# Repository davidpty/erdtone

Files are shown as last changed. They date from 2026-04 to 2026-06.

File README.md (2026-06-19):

# ErdTone

Bring a vintage rotary phone back to life on a modern telephone exchange. ErdTone converts pulse dialing to DTMF tones in real time, running on a single ATtiny85 hidden inside the phone with no visible modifications.

Built around the Siemens W48 with full support for the `Earth key` (German: Erdtaste), it goes beyond basic pulse conversion with last-number redial, speed-dial, Direct Dial Mode, auto-dial on pickup, `*` and `#` hold gestures, pause support, and adjustable DTMF timing. Everything is configured directly from the rotary dial - no computer needed after flashing.

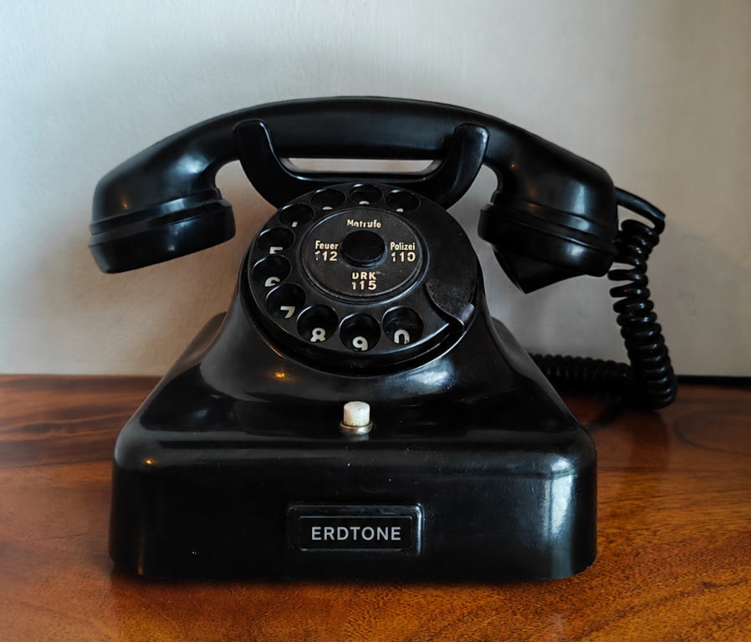
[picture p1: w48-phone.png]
Siemens W48 rotary phone


This project is a fork of the rotarydial firmware, extended with Earth key support, auto-dial, speed-dial, Direct Dial Mode, and configurable DTMF and menu timing.

## Hardware

Needed build parts:

* 1x ATTINY85V
* 1x 78L05 5V regulator
* 1x 4 MHz crystal
* 1x 680 ohm resistor
* 1x 27 V 1 W zener diode
* 2x 22 pF ceramic capacitors
* 4x 0.1 uF (100 nF) ceramic capacitors
* 1x 4 position terminal
* 1x 1N4007 diode

## Circuit

A Fritzing layout is included with a compact footprint designed to fit inside the W48 housing without modifications. See `ErdTone.fzz`.

## Wiring

### Rotary dial

* Disconnect the rotary dial from the phone circuitry. Do not connect it in parallel with the original phone circuit.
* Connect it to the converter:

  * Pulse contact, normally closed and opening for each pulse, to `PULSE`
  * Dial contact, closed while the dial is moving, to `DIAL`

### Earth key

* Disconnect the `Earth key` from the phone circuitry.
* Connect it to the same `DIAL` line used by the rotary dial:

  * One side to `DIAL`
  * Other side to `GND`
* Pressing the `Earth key` must pull `DIAL` to `GND`.

### Power

* Connect power after the hookswitch:

  * Line `+` to `VCC`
  * Line `-` to `GND`
* The device must be off when the phone is on-hook.
* Optional: add a diode, for example 1N4007, between line `+` and `VCC` for protection:

  * Anode to line `+`
  * Cathode to `VCC`

## Build

Install tools:

```bash
sudo apt update && sudo apt install gcc-avr avr-libc binutils-avr avrdude make
```

Build, flash and set fuses:

```bash
make install              # default 4 MHz external crystal
make CLOCK_MODE=8 install # 8 MHz internal oscillator, for testing only
```

Erase EEPROM, clearing all stored numbers and settings:

```bash
make erase
```

## Operation

### Normal dialing

Dial a number and release. The firmware sends the matching DTMF tone.

If you pause for more than about 3 seconds between digits, a pause is automatically inserted into the redial memory at that point. If you wait more than about 6 seconds, two pauses are inserted. This allows redial to correctly replay numbers that require waiting for an automated phone menu or office switchboard to respond.

### Earth key

The `Earth key` is a quick redial and speed-dial shortcut.

* Brief press and release: redial the last number
* Hold until the first beep: dial the stored Earth key speed-dial number
* Hold until the second beep: program the Earth key speed-dial number
* Press during startup: cancel auto-dial for that cycle

### Rotary hold menu

Use the rotary dial for special functions.

Dial a digit and hold until the first beep, then release:

* `1` = send `*`
* `2` = send `#`
* `3` = redial last number
* `4` to `9`, `0` = dial the stored speed-dial number

Keep holding until the second beep:

* `4` to `9`, `0` = enter programming mode for that speed-dial slot
* `1` = cycle DTMF tone duration, 80 ms or 200 ms
* `2` = cycle menu hold time, 1 s or 2 s
* `3` = enter auto-dial setup

### Speed-dial programming

1. Dial the slot digit.
2. Keep holding until the second beep, then release.
3. Enter the number one digit at a time.
4. Release after each digit.
5. Hang up when done.

Notes:

* Each digit is written to EEPROM immediately.
* `*`, `#`, and pause can be stored by dialing `1`, `2`, or `3`, holding until the first beep, then releasing.
* The Earth key has its own dedicated speed-dial slot, programmed by holding the Earth key until the second beep.
* During programming, you can copy into the current slot:

  * Press the `Earth key` to load the last dialed number.
  * Dial a source speed-dial slot, `4` to `9` or `0`, and hold until the first beep.
* Hold `0` until the second beep to clear the current slot. This also works for the Earth key slot.

### Auto-dial setup

Auto-dial is stored in one of the speed-dial slots and dials automatically after power-up if enabled.

Set auto-dial:

1. Dial `3`.
2. Hold until the second beep, then release.
3. Dial the speed-dial slot, or press the `Earth key` to use the Earth key speed-dial number as the auto-dial number.
4. The auto-dial is saved with the default 5 second delay.
5. Optional: dial a delay digit from `0` to `9` to override the delay.

Clear auto-dial:

1. Dial `3`.
2. Hold until the second beep, then release.
3. Hold `0` until the second beep, then release.

Pressing the `Earth key` or starting to dial during startup cancels auto-dial for that cycle.

## Service Codes

Service codes are entered during a normal call using the rotary hold menu for `*` and `#`.

### Direct Dial Mode

Direct Dial Mode turns digits `4` to `9` and `0` into instant speed-dial keys. Pressing any of them immediately dials the stored number without holding. The Earth key also dials its assigned speed-dial slot directly.

Set it up with a 3-digit PIN `PPP`, using digits `0` to `9` only:

* `**PPP` enables Direct Dial with Programming Lock:

  * Normal dialing still works.
  * Speed-dial programming, settings changes, and factory reset are blocked.
* `*#PPP` enables Direct Dial Only:

  * Normal dialing is blocked.
  * Digits `4` to `9` and `0` directly dial their assigned speed-dial slots.
  * The Earth key directly dials the Earth key speed-dial slot.
  * Speed-dial programming, settings changes, and factory reset are blocked.

Disable the active lock mode:

* `**PPP` or `*#PPP` with the correct PIN permanently disables the active lock mode and clears the PIN.
* `##PPP` with the correct PIN temporarily disables the active lock mode for the current call only.

To enter a PIN when Direct Dial Only is active:

1. Dial `*` or `#` twice via first-level hold as the first two actions after pickup.
2. Any combination works: `**`, `##`, `*#`, or `#*`.
3. This arms PIN entry mode.
4. Dial the three PIN digits directly.
5. These digits feed the PIN sequence without triggering any speed-dial slot.

Use `**PPP` or `*#PPP` to permanently disable the active lock mode, or `##PPP` to disable it for the current call only.

### Factory reset

Dial `*#0#*` to erase all stored numbers, speed-dial slots, auto-dial configuration, and reset DTMF duration and menu hold time to defaults.

Factory reset is blocked when a lock mode is active.

## Credits

ErdTone builds on the work of [Boris Cherkasskiy](http://boris0.blogspot.ca/2013/09/rotary-dial-for-digital-age.html), who created the original firmware in 2011, [Arnie Weber](https://bitbucket.org/310weber/rotary_dial/), who reworked the hardware in 2015, and [Matthew Millman](http://tech.mattmillman.com/), who cleaned up the implementation in 2018.

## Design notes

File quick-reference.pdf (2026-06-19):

W48 - ErdTone - Quick Reference

DR: Dial & Release
H1: Hold -> 1st beep
H2: Hold -> 2nd beep

Normal dialing (DR)

DR: 0-9 | DTMF tone sent
Pause >3 s | Stores a pause in redial

Earth key (Erdtaste)

Short press Redial last number

H1 | Dial Earth key slot
H2 | Program Earth key slot
Press at pickup | Cancel auto-dial for this session

H1 actions

H1: 1 | Send *

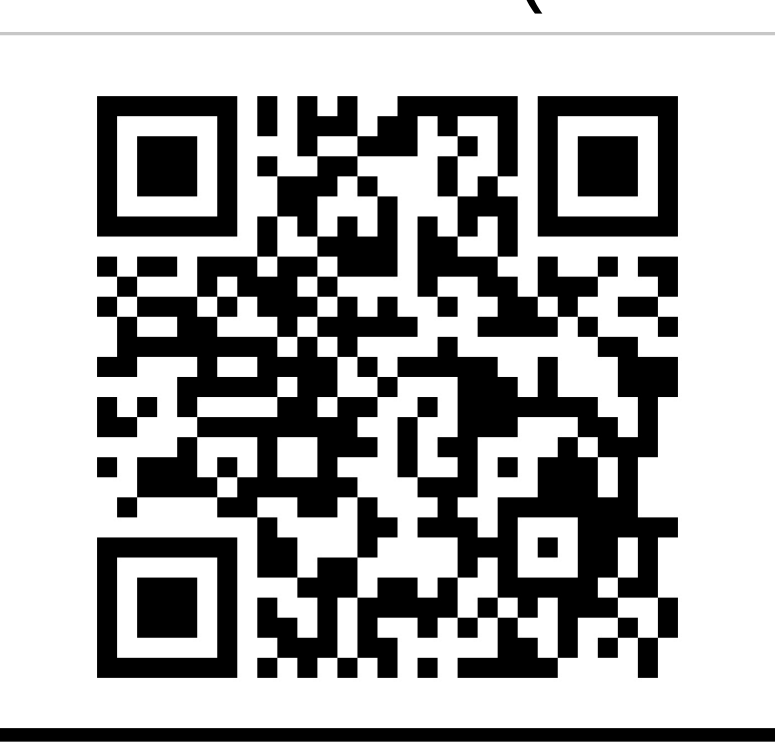
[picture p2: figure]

H1: 2 | Send #
H1: 3 | Redial last number
H1: 4-9,0 | Dial speed-dial slot

Programming (H2 to enter)

H2 actions

H2: 4-9,0 | Enter slot programming
H2: 1 | Toggle DTMF 80/200 ms
H2: 2 | Toggle hold 1/2 s
H2: 3 | Enter auto-dial setup
During slot programming
DR: 0-9 | Store digit
H1: 1 or 2 | Store * or #
H1: 3 | Store pause
H1: 4-9,0 | Copy speed-dial slot
Earth key | Copy last dialed
H2: 0 | Clear this slot
Hang up | Save & exit
During auto-dial setup
1. Select # | Earth key slot or speed-dial slot 4-9, 0
2. Set delay | Dial 0-9 seconds
H2: 0 | Clear auto-dial

Service codes (* # via H1)

Set lock (no PIN set)

**PIN | Lock programming
*#PIN | Lock programming and dialing
PIN | 3 digits from 0-9
Unlock (* # via H1)
**PIN | Permanent unlock
##PIN | Unlock for this call only

Fully locked mode

DR: 4-9,0 | Dial speed-dial

DR: Earth key Dial Earth key slot

DR: 1,2,3 | No action

Factory reset

*#0#* | Erase all (blocked if locked)

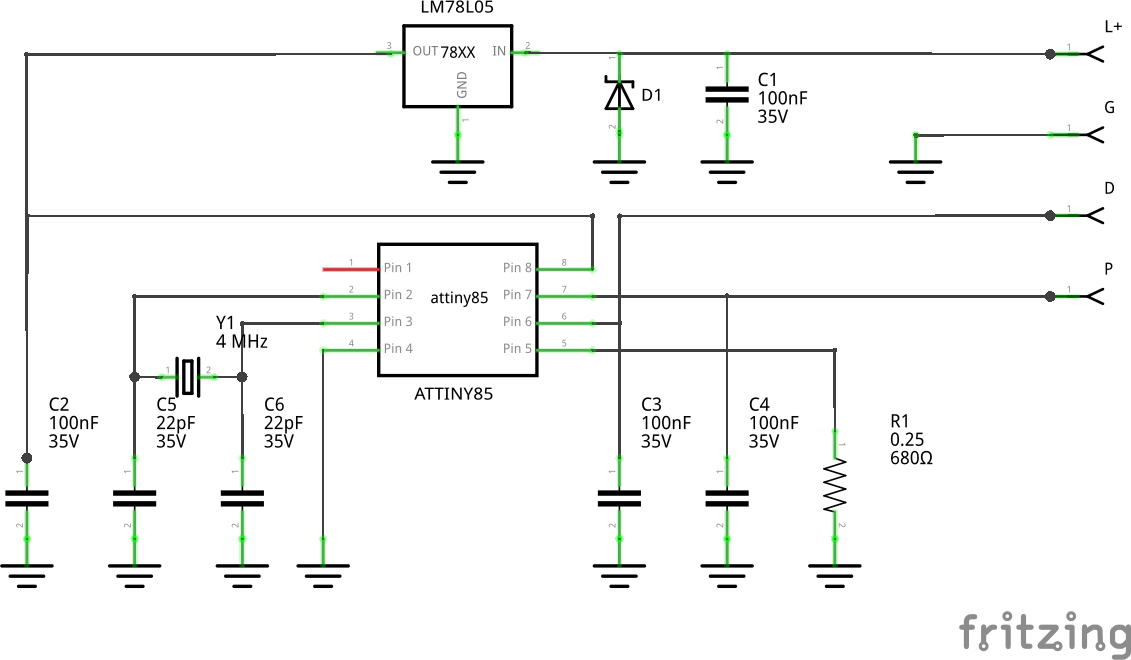
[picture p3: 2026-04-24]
pcb-schematic.png

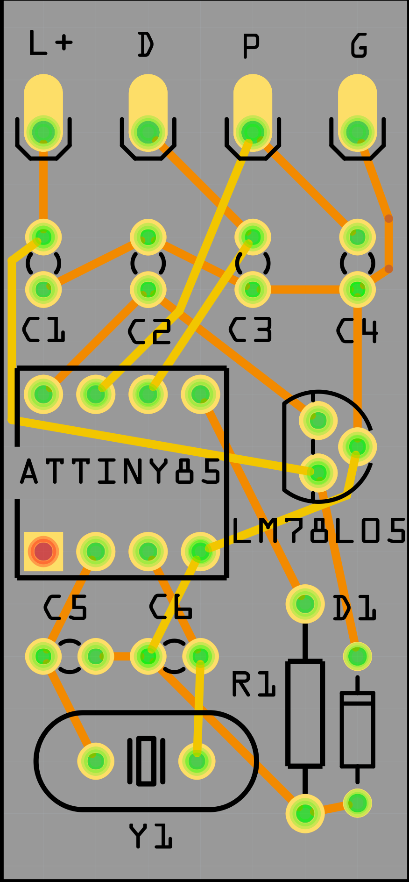
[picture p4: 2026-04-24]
pcb-layout.png

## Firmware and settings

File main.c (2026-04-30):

//*****************************************************************************
// Title        : Pulse to tone (DTMF) converter
// Author       : Boris Cherkasskiy
//                http://boris0.blogspot.ca/2013/09/rotary-dial-for-digital-age.html
// Created      : 2011-10-24
//
// Modified     : Arnie Weber 2015-06-22
//                https://bitbucket.org/310weber/rotary_dial/
//                NOTE: This code is not compatible with Boris's original hardware
//                due to changed pin-out (see Eagle files for details)
//
// Modified     : Matthew Millman 2018-05-29
//                http://tech.mattmillman.com/
//                Cleaned up implementation, modified to work more like the
//                Rotatone commercial product.
//
// Modified     : davidpty 2026-04-23
//                added hotdial, lock dial and support for 'Erdtaste' 
//
// This code is distributed under the GNU Public License
// which can be found at http://www.gnu.org/licenses/gpl.txt
//
// DTMF generator logic is loosely based on the AVR314 app note from Atmel
//
//*****************************************************************************

// Uncomment to build with reverse dial
//#define NZ_DIAL

#include <stdbool.h>
#include <stdint.h>
#include <avr/io.h>
#include <avr/interrupt.h>
#include <avr/sleep.h>
#include <avr/wdt.h>
#include <util/delay.h>
#include <avr/eeprom.h>
#include <string.h>

#include "dtmf.h" 

#define PIN_DIAL                    PB1
#define PIN_PULSE                   PB2

#define SPEED_DIAL_SIZE             42

#define STATE_DIAL                  0x00
#define STATE_SPECIAL_L1            0x01
#define STATE_SPECIAL_L2            0x02
#define STATE_PROGRAM_SD            0x03
#define STATE_HOTLINE_SLOT          0x04
#define STATE_HOTLINE_DELAY         0x05
#define STATE_PROGRAM_ERDTASTE      0x06

#define F_NONE                      0x00
#define F_DETECT_SPECIAL_L1         0x01
#define F_DETECT_SPECIAL_L2         0x02
#define F_WDT_AWAKE                 0x04

#define SLEEP_64MS                  0x00
#define SLEEP_128MS                 0x01
#define SLEEP_1S                    0x02
#define SLEEP_2S                    0x03

#define SPECIAL_L2_HOLD_TIME        SLEEP_2S

#define DTMF_DURATION_MS_SHORT      80
#define DTMF_DURATION_MS_LONG       200
#define DTMF_PAUSE_MS               2000  // Pause inserted in speed dial memory

#define PAUSE_DETECT_HOLD_TIME      SLEEP_2S  // ~2s WDT interval for pause detection
#define F_DETECT_PAUSE              0x08

#define SPEED_DIAL_COUNT            9   // 9 Positions in total (Redail(3),4,5,6,7,8,9,0 and Erdtaste)
#define SPEED_DIAL_ERDTASTE         (SPEED_DIAL_COUNT - 2)   // slot 7
#define SPEED_DIAL_REDIAL           (SPEED_DIAL_COUNT - 1)   // slot 8

#define L2_STAR                     1
#define L2_POUND                    2
#define L2_REDIAL                   3

#define LOCK_NONE                   0
#define LOCK_PROGRAM                1
#define LOCK_FULL                   2

typedef struct
{
    uint8_t enabled;
    uint8_t slot_digit;
    uint8_t delay_digit;
} hotline_config_t;

typedef struct
{
    uint8_t state;
    uint8_t flags;
    bool dial_pin_state;
    bool suppress_first_release;
    bool program_special_insert;
    bool special_l1_latched;
    uint8_t lock_state;
    int8_t speed_dial_digits[SPEED_DIAL_SIZE];
    int8_t dialed_digit;
    int8_t service_code_buf[5];
    uint8_t special_hold_state;
    uint8_t speed_dial_index;
    uint8_t speed_dial_digit_index;
    uint8_t hotline_slot_digit;
    uint8_t l1_hold_time;
    uint8_t pending_pauses;
    uint16_t dtmf_duration;
} runstate_t;

static void init(void);
static void process_dialed_digit(runstate_t *rs);
static void read_speed_dial(uint8_t slot, int8_t *buf);
static void write_speed_dial(uint8_t slot, int8_t *buf);
static uint8_t find_end(int8_t *buf);
static void load_into_current_slot(int8_t *src, runstate_t *rs);
static bool is_programming_state(uint8_t state);
static uint8_t current_program_slot(runstate_t *rs);
static void clear_current_program_buffer(runstate_t *rs);
static void store_digit_to_redial(runstate_t *rs, int8_t digit);
static void push_to_service_buffer(runstate_t *rs, int8_t digit);
static void clear_speed_dial_slot(runstate_t *rs, uint8_t slot_index);
static void append_digit_to_slot(runstate_t *rs, int8_t digit, uint8_t tone);
static void handle_dial_state(runstate_t *rs, int8_t *digit_to_buffer);
static bool handle_program_special_insert(runstate_t *rs);
static bool handle_special_l1_state(runstate_t *rs, int8_t *digit_to_buffer);
static void handle_special_l2_state(runstate_t *rs);
static void handle_programming_state(runstate_t *rs);
static void handle_hotline_slot_state(runstate_t *rs);
static void handle_hotline_delay_state(runstate_t *rs);
static void load_hotline_config(hotline_config_t *config);
static void write_hotline_config(const hotline_config_t *config);
static uint16_t hotline_delay_ms(uint8_t delay_digit);
static bool wait_for_hotline_window(uint16_t delay_ms);
static void suppress_first_release_if_needed(runstate_t *rs, bool dial_pin_state);
static void maybe_dial_hotline(void);
static void dial_speed_dial_number(int8_t *speed_dial_digits, int8_t index, uint16_t dtmf_duration);
static void flush_pending_pauses(runstate_t *rs);
static void check_service_codes(runstate_t *rs);
static void handle_factory_reset(runstate_t *rs);
static bool dial_locked(runstate_t *rs);
static bool programming_locked(runstate_t *rs);
static bool pin_matches(runstate_t *rs, const uint8_t *pin);
static void clear_lock(runstate_t *rs);
static void handle_lock_code(runstate_t *rs, uint8_t requested_lock);
static void handle_session_unlock(runstate_t *rs);
static void wdt_timer_start(uint8_t delay);
static void start_sleep(void);
static void wdt_stop(void);
static bool in_pin_entry_mode(runstate_t *rs);

// Map speed dial numbers to memory locations
const int8_t _g_speed_dial_loc[] =
{
    0,
    -1 /* 1 - * */,
    -1 /* 2 - # */,
    -1 /* 3 - Redial */,
    1,
    2,
    3,
    4,
    5,
    6 
};

typedef struct
{
    int8_t code[5];
    uint8_t action;
} service_code_t;

#define SERVICE_FACTORY_RESET   0

static const service_code_t _g_service_codes[] =
{
    { { DIGIT_STAR, DIGIT_POUND, 0, DIGIT_POUND, DIGIT_STAR }, SERVICE_FACTORY_RESET },
};

int8_t EEMEM _g_speed_dial_eeprom[SPEED_DIAL_COUNT][SPEED_DIAL_SIZE] = { [0 ... (SPEED_DIAL_COUNT - 1)][0 ... SPEED_DIAL_SIZE - 1] = DIGIT_OFF };
hotline_config_t EEMEM _g_hotline_eeprom = { 0, 0, 5 };
uint8_t EEMEM _g_dtmf_duration_eeprom = 0;   // 0=DTMF_DURATION_MS_SHORT, 1=DTMF_DURATION_MS_LONG
uint8_t EEMEM _g_l1_hold_time_eeprom = 0;    // 0=SPECIAL_L1_HOLD_TIME_LONG, 1=SPECIAL_L1_HOLD_TIME_SHORT
uint8_t EEMEM _g_lock_pin_eeprom[3] = { DIGIT_OFF, DIGIT_OFF, DIGIT_OFF };
uint8_t EEMEM _g_lock_state_eeprom = 0;
runstate_t _g_run_state;

int main(void)
{
    runstate_t *rs = &_g_run_state;
    bool dial_pin_prev_state;
    rs->pending_pauses = 0;
    uint8_t lock_state = eeprom_read_byte(&_g_lock_state_eeprom);
    if (lock_state > LOCK_FULL) lock_state = LOCK_NONE;
    rs->lock_state = lock_state;
    init();

    // Wait for the decoupling capacitors to charge
    wdt_timer_start(SLEEP_128MS);
    start_sleep();
    wdt_stop();

    dtmf_init();

    // Local dial status variables 
    rs->state = STATE_DIAL;
    rs->dial_pin_state = true;
    rs->flags = F_NONE;
    rs->special_hold_state = STATE_DIAL;
    rs->suppress_first_release = false;
    rs->special_l1_latched = false;
    for (uint8_t i = 0; i < 5; i++)
        rs->service_code_buf[i] = DIGIT_OFF;
    rs->program_special_insert = false;
    rs->speed_dial_digit_index = 0;
    rs->speed_dial_index = 0;
    rs->hotline_slot_digit = DIGIT_OFF;

    uint8_t dtmf_dur_index = eeprom_read_byte(&_g_dtmf_duration_eeprom);
    if (dtmf_dur_index >= 2) dtmf_dur_index = 0;
    rs->dtmf_duration = (dtmf_dur_index == 0) ? DTMF_DURATION_MS_SHORT : DTMF_DURATION_MS_LONG;

    uint8_t l1_hold_index = eeprom_read_byte(&_g_l1_hold_time_eeprom);
    if (l1_hold_index >= 2) l1_hold_index = 0;
    rs->l1_hold_time = (l1_hold_index == 0) ? SLEEP_2S : SLEEP_1S;
    
    dial_pin_prev_state = true;
    
    for (uint8_t i = 0; i < SPEED_DIAL_SIZE; i++)
        rs->speed_dial_digits[i] = DIGIT_OFF;

//#define DEBUG
    #ifdef DEBUG
        // DEBUG: beep speed_dial_digit_index times to show redial buffer fill level
        {
            int8_t tmp[SPEED_DIAL_SIZE];
            read_speed_dial(SPEED_DIAL_REDIAL, tmp);
            uint8_t count = 0;
            while (count < SPEED_DIAL_SIZE && tmp[count] != DIGIT_OFF)
                count++;
            for (uint8_t i = 0; i < count; i++)
            {
                dtmf_generate_tone(DIGIT_BEEP_LOW, 80);
                sleep_ms(200);
            }
            sleep_ms(1000);
        }
    #endif

    maybe_dial_hotline();

    while (1)
    {
        rs->dial_pin_state = bit_is_set(PINB, PIN_DIAL);

        bool suppressed = rs->suppress_first_release;

        suppress_first_release_if_needed(rs, rs->dial_pin_state);
        if (rs->special_l1_latched && !rs->dial_pin_state)
        {
            dial_pin_prev_state = rs->dial_pin_state;
            continue;
        }
        // Skip if flag was set BEFORE clearing - prevents redial on first release
        if (suppressed)
        {
            dial_pin_prev_state = rs->dial_pin_state;
            continue;
        }

        if (dial_pin_prev_state != rs->dial_pin_state) 
        {
            if (!rs->dial_pin_state) 
            {
                // Dial just started
                if (!rs->special_l1_latched)
                    rs->flags |= F_DETECT_SPECIAL_L1;
                rs->flags &= ~F_DETECT_PAUSE; 
                rs->dialed_digit = 0;
 
                wdt_timer_start(SLEEP_64MS);
                start_sleep();
            }
            else 
            {
                // Disable SF detection (should be already disabled)
                rs->flags &= ~(F_DETECT_SPECIAL_L1 | F_DETECT_SPECIAL_L2);

                // Check that we detect a valid digit
                if (rs->dialed_digit <= 0 || rs->dialed_digit > 10)
                {
                    rs->dialed_digit = DIGIT_OFF;
    
                    if (rs->state == STATE_SPECIAL_L1)
                    {
                        // Erdtaste L1 - dial Erdtaste speed dial
                        wdt_stop();
                        dial_speed_dial_number(rs->speed_dial_digits, SPEED_DIAL_ERDTASTE, rs->dtmf_duration);
                        rs->state = STATE_DIAL;
                    }
                    else if (rs->state == STATE_SPECIAL_L2)
                    {
                        if (programming_locked(rs))
                        {
                            dtmf_generate_tone(DIGIT_TUNE_DESC, 200);
                            rs->state = STATE_DIAL;
                        }
                        else
                        {
                            // Erdtaste L2 - enter Erdtaste speed dial programming
                            wdt_stop();
                            rs->speed_dial_index = SPEED_DIAL_ERDTASTE;
                            rs->special_hold_state = STATE_PROGRAM_ERDTASTE;
                            clear_current_program_buffer(rs);
                            rs->state = STATE_PROGRAM_ERDTASTE;
                        }
                    }
                    else if (is_programming_state(rs->state))
                    {
                        // Erdtaste short press during programming - load redial into buffer
                        wdt_stop();
                        read_speed_dial(SPEED_DIAL_REDIAL, rs->speed_dial_digits);
                        load_into_current_slot(rs->speed_dial_digits, rs);
                        // Stay in current programming state
                    }        
                    else if (rs->state == STATE_HOTLINE_SLOT)
                    {
                        // Erdtaste short press during hotline slot selection - use Erdtaste slot as hotline
                        wdt_stop();
                        rs->hotline_slot_digit = DIGIT_OFF;  // no dial digit, special marker
                        rs->state = STATE_HOTLINE_DELAY;
                        dtmf_generate_tone(DIGIT_BEEP_LOW, rs->dtmf_duration);

                        hotline_config_t config;
                        config.enabled = 1;
                        config.slot_digit = DIGIT_OFF;  // special value meaning Erdtaste slot
                        config.delay_digit = 5;
                        write_hotline_config(&config);
                    }                                    
                    else if (rs->state == STATE_DIAL && !rs->suppress_first_release)
                    {
                        wdt_stop();
                        if (dial_locked(rs))
                        {
                            // Locked: Erdtaste dials the Erdtaste speed-dial slot directly
                            dial_speed_dial_number(rs->speed_dial_digits, SPEED_DIAL_ERDTASTE, rs->dtmf_duration);
                        }
                        else
                        {
                            // Normal: Erdtaste triggers redial
                            read_speed_dial(SPEED_DIAL_REDIAL, rs->speed_dial_digits);
                            dial_speed_dial_number(rs->speed_dial_digits, SPEED_DIAL_REDIAL, rs->dtmf_duration);
                        }
                    }
                    else
                    {
                        rs->suppress_first_release = false;
                        wdt_timer_start(SLEEP_64MS);
                        start_sleep();
                    }
                }
                else 
                {
                    // Got a valid digit - process it            
#ifdef NZ_DIAL
                    // NZPO Phones only. 0 is same as GPO but 1-9 are reversed.
                    rs->dialed_digit = (10 - rs->dialed_digit);
#else
                    if (rs->dialed_digit == 10)
                        rs->dialed_digit = 0; // 10 pulses => 0
#endif
                    wdt_timer_start(SLEEP_128MS);
                    start_sleep();
                    wdt_stop();

                    process_dialed_digit(rs);
                }

                rs->special_l1_latched = false;
            }    
        } 
        else 
        {
            if (rs->dial_pin_state) 
            {
                // Rotary dial at the rest position
                // Reset all variables
                rs->state = STATE_DIAL;
                rs->special_hold_state = STATE_DIAL;
                rs->flags &= ~(F_DETECT_SPECIAL_L1 | F_DETECT_SPECIAL_L2);
                rs->dialed_digit = DIGIT_OFF;
            }
        }

        dial_pin_prev_state = rs->dial_pin_state;

        // Don't power down if special function detection is active        
        if (rs->flags & F_DETECT_SPECIAL_L1)
        {
            rs->flags &= ~F_WDT_AWAKE;
            // Put MCU to sleep - to be awoken either by pin interrupt or WDT
            wdt_timer_start(rs->l1_hold_time);
            start_sleep();

            // Special function mode detected?
            if (rs->flags & F_WDT_AWAKE)
            {
                // SF mode detected
                rs->flags &= ~F_WDT_AWAKE;
                rs->special_hold_state = rs->state;
                if (is_programming_state(rs->state))
                    rs->program_special_insert = true;
                rs->state = STATE_SPECIAL_L1;
                rs->flags &= ~F_DETECT_SPECIAL_L1;
                if (!programming_locked(rs))
                    rs->flags |= F_DETECT_SPECIAL_L2;
                else
                {
                    rs->special_l1_latched = true;
                    wdt_stop();
                }

                // Indicate that we entered L1 SF mode with short beep
                dtmf_generate_tone(DIGIT_BEEP_LOW, 200);
            }
            else
            {
                // Released before the first timeout: cancel special detection so a
                // short press can be handled as redial on the next loop.
                rs->flags &= ~F_DETECT_SPECIAL_L1;
            }
        }
        else if (rs->flags & F_DETECT_SPECIAL_L2)
        {
            rs->flags &= ~F_WDT_AWAKE;
            // Put MCU to sleep - to be awoken either by pin interrupt or WDT
            wdt_timer_start(SPECIAL_L2_HOLD_TIME);
            start_sleep();

            if (rs->flags & F_WDT_AWAKE)
            {
                // SF mode detected
                rs->flags &= ~F_WDT_AWAKE;
                rs->state = STATE_SPECIAL_L2;
                rs->flags &= ~F_DETECT_SPECIAL_L2;

                // Indicate that we entered L2 SF mode with asc tone
                dtmf_generate_tone(DIGIT_TUNE_ASC, 200);
            }
            else
            {
                // Released before the second timeout: cancel special detection.
                rs->flags &= ~F_DETECT_SPECIAL_L2;
            }
        }        
        else if (rs->flags & F_DETECT_PAUSE)
        {
            rs->flags &= ~F_WDT_AWAKE;
            wdt_timer_start(PAUSE_DETECT_HOLD_TIME);
            start_sleep();

            if (rs->flags & F_WDT_AWAKE)
            {
                rs->flags &= ~F_WDT_AWAKE;
                if (rs->pending_pauses < 2)
                {
                    rs->pending_pauses++;
                    if (rs->pending_pauses >= 2)
                    {
                        rs->flags &= ~F_DETECT_PAUSE;  // max pauses reached, stop
                        wdt_stop();
                    }
                        
                }
            }
            else
            {
                // Woken by pin interrupt (dial activity) - cancel pause detection
                rs->flags &= ~F_DETECT_PAUSE;
            }
        }
        else
        {
            // Don't need timer - sleep to power down mode
            set_sleep_mode(SLEEP_MODE_PWR_DOWN);
            sleep_mode();
        }
    }

    return 0;
}

// New speed-dial buffer helpers: keep EEPROM layout and END-marker behavior centralized.
static void read_speed_dial(uint8_t slot, int8_t *buf)
{
    if (slot < SPEED_DIAL_COUNT)
        eeprom_read_block(buf, &_g_speed_dial_eeprom[slot][0], SPEED_DIAL_SIZE);
}

static void write_speed_dial(uint8_t slot, int8_t *buf)
{
    if (slot < SPEED_DIAL_COUNT)
        eeprom_update_block(buf, &_g_speed_dial_eeprom[slot][0], SPEED_DIAL_SIZE);
}

static uint8_t find_end(int8_t *buf)
{
    uint8_t index = 0;

    while (index < SPEED_DIAL_SIZE && buf[index] >= 0)
        index++;

    return index;
}

static bool is_programming_state(uint8_t state)
{
    return state == STATE_PROGRAM_SD || state == STATE_PROGRAM_ERDTASTE;
}

static uint8_t current_program_slot(runstate_t *rs)
{
    if (rs->state == STATE_PROGRAM_ERDTASTE || rs->special_hold_state == STATE_PROGRAM_ERDTASTE)
        return SPEED_DIAL_ERDTASTE;

    return rs->speed_dial_index;
}

static void clear_current_program_buffer(runstate_t *rs)
{
    for (uint8_t i = 0; i < SPEED_DIAL_SIZE; i++)
        rs->speed_dial_digits[i] = DIGIT_OFF;

    rs->speed_dial_digit_index = 0;
}

static void load_into_current_slot(int8_t *src, runstate_t *rs)
{
    for (uint8_t i = 0; i < SPEED_DIAL_SIZE; i++)
        rs->speed_dial_digits[i] = src[i];

    rs->speed_dial_digit_index = find_end(rs->speed_dial_digits);
    write_speed_dial(current_program_slot(rs), rs->speed_dial_digits);

    for (uint8_t i = 0; i < rs->speed_dial_digit_index; i++)
    {
        dtmf_generate_tone(DIGIT_BEEP_LOW, rs->dtmf_duration);
        sleep_ms(rs->dtmf_duration);
    }
}

static void store_digit_to_redial(runstate_t *rs, int8_t digit)
{
    if (rs->speed_dial_digit_index < SPEED_DIAL_SIZE)
    {
        rs->speed_dial_digits[rs->speed_dial_digit_index] = digit;
        rs->speed_dial_digit_index++;
        write_speed_dial(SPEED_DIAL_REDIAL, rs->speed_dial_digits);
        if (digit != DIGIT_PAUSE)
        {
            rs->pending_pauses = 0;
            rs->flags |= F_DETECT_PAUSE;
        }
    }
}

static void push_to_service_buffer(runstate_t *rs, int8_t digit)
{
    for (uint8_t i = 0; i < 4; i++) {
        rs->service_code_buf[i] = rs->service_code_buf[i + 1];
    }
    rs->service_code_buf[4] = digit;
}
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

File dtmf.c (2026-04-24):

//*****************************************************************************
// Title        : Pulse to tone (DTMF) converter
// Author       : Boris Cherkasskiy
//                http://boris0.blogspot.ca/2013/09/rotary-dial-for-digital-age.html
// Created      : 2011-10-24
//
// Modified     : Arnie Weber 2015-06-22
//                https://bitbucket.org/310weber/rotary_dial/
//                NOTE: This code is not compatible with Boris's original hardware
//                due to changed pin-out (see Eagle files for details)
//
// Modified     : Matthew Millman 2018-05-29
//                http://tech.mattmillman.com/
//                Cleaned up implementation, modified to work more like the
//                Rotatone product.
//
// This code is distributed under the GNU Public License
// which can be found at http://www.gnu.org/licenses/gpl.txt
//
// DTMF generator logic is loosely based on the AVR314 app note from Atmel
//
//*****************************************************************************

#include <stdbool.h>
#include <stdint.h>
#include <avr/interrupt.h>
#include <avr/sleep.h>

#include "dtmf.h"

#define TIMER_CLK_DIV1              0x01    ///< Timer clocked at F_CPU
#define TIMER_PRESCALE_MASK0        0x07    ///< Timer Prescaler Bit-Mask
#define NUM_SAMPLES                 128     // Number of samples in lookup table


static void dtmf_enable_pwm(void);

//************************** SIN TABLE *************************************
// Samples table : one period sampled on 128 samples and
// quantized on 7 bit
//**************************************************************************
const uint8_t auc_sin_param[NUM_SAMPLES] = {
    64,  67,  70,  73,
    76,  79,  82,  85,
    88,  91,  94,  96,
    99,  102, 104, 106,
    109, 111, 113, 115,
    117, 118, 120, 121,
    123, 124, 125, 126,
    126, 127, 127, 127,
    127, 127, 127, 127,
    126, 126, 125, 124,
    123, 121, 120, 118,
    117, 115, 113, 111,
    109, 106, 104, 102,
    99,  96,  94,  91,
    88,  85,  82,  79,
    76,  73,  70,  67,
    64,  60,  57,  54,
    51,  48,  45,  42,
    39,  36,  33,  31,
    28,  25,  23,  21,
    18,  16,  14,  12,
    10,  9,   7,   6,
    4,   3,   2,   1,
    1,   0,   0,   0,
    0,   0,   0,   0,
    1,   1,   2,   3,
    4,   6,   7,   9,
    10,  12,  14,  16,
    18,  21,  23,  25,
    28,  31,  33,  36,
    39,  42,  45,  48,
    51,  54,  57,  60
};

//***************************  x_SW  ***************************************
// Fck = Xtal/prescaler
// Table of x_SW (excess 8): x_SW = ROUND(8 * N_samples * f * 510 / Fck)
//**************************************************************************

// high frequency
// 1209hz  ---> x_SW = 79
// 1336hz  ---> x_SW = 87
// 1477hz  ---> x_SW = 96
// 1633hz  ---> x_SW = 107
//
// low frequency
// 697hz  ---> x_SW = 46
// 770hz  ---> x_SW = 50
// 852hz  ---> x_SW = 56
// 941hz  ---> x_SW = 61
//
//      | 1209 | 1336 | 1477 | 1633
//  697 |   1  |  2   |   3  |   A
//  770 |   4  |  5   |   6  |   B
//  852 |   7  |  8   |   9  |   C
//  941 |   *  |  0   |   #  |   D

#if F_CPU == 8000000
const uint8_t auc_frequency[12][2] =
{
    { 44, 31 }, // 0
    { 40, 23 }, // 1
    { 44, 23 }, // 2
    { 48, 23 }, // 3
    { 40, 25 }, // 4
    { 44, 25 }, // 5
    { 48, 25 }, // 6
    { 40, 28 }, // 7
    { 44, 28 }, // 8
    { 48, 28 }, // 9
    { 40, 31 }, // *
    { 48, 31 }, // #
};
#else
const uint8_t auc_frequency[12][2] =
{
    { 87, 61 }, // 0
    { 79, 46 }, // 1
    { 87, 46 }, // 2
    { 96, 46 }, // 3
    { 79, 50 }, // 4
    { 87, 50 }, // 5
    { 96, 50 }, // 6
    { 79, 56 }, // 7
    { 87, 56 }, // 8
    { 96, 56 }, // 9
    { 79, 61 }, // *
    { 96, 61 }, // #
};
#endif

volatile uint32_t _g_delay_counter;         // Delay counter for sleep function
volatile uint8_t _g_stepwidth_a;                // step width of high frequency
volatile uint8_t _g_stepwidth_b;                // step width of low frequency
volatile uint16_t _g_cur_sin_val_a;             // position freq. A in LUT (extended format)
volatile uint16_t _g_cur_sin_val_b;             // position freq. B in LUT (extended format)

void dtmf_init(void)
{
    TIMSK = _BV(TOIE0);                 // Int T0 Overflow enabled
    TCCR0A = _BV(WGM00) | _BV(WGM01);   // 8Bit PWM; Compare/match output mode configured later
    TCCR0B = TIMER_PRESCALE_MASK0 & TIMER_CLK_DIV1;
    TCNT0 = 0;
    OCR0A = 0;
    DDRB |= _BV(PIN_PWM_OUT);    // PWM output (OC0A pin)

    _g_stepwidth_a = 0x00;
    _g_stepwidth_b = 0x00;

    _g_cur_sin_val_a = 0;
    _g_cur_sin_val_b = 0;

    _g_delay_counter = 0;
}

// Generate DTMF tone, duration x ms
void dtmf_generate_tone(int8_t digit, uint16_t duration_ms)
{
    GIMSK = 0; 

    if (digit >= 0 && digit <= DIGIT_POUND)
    {
        // Standard digits 0-9, *, #
        _g_stepwidth_a = auc_frequency[digit][0];  
        _g_stepwidth_b = auc_frequency[digit][1]; 
        dtmf_enable_pwm();

        // Wait x ms
        sleep_ms(duration_ms);
    } 
    else if (digit == DIGIT_BEEP)
    {
        // Beep ~1000Hz (66)
        _g_stepwidth_a = 66;  
        _g_stepwidth_b = 0;
        dtmf_enable_pwm();

        // Wait x ms
        sleep_ms(duration_ms);
    }
    else if (digit == DIGIT_BEEP_LOW)
    {
        // Beep ~500Hz (33)
        _g_stepwidth_a = 33;  
        _g_stepwidth_b = 0;
        dtmf_enable_pwm();

        // Wait x ms
        sleep_ms(duration_ms);
    }
    else if (digit == DIGIT_TUNE_ASC)
    {
        _g_stepwidth_a = 34;    // C=523.25Hz  
        _g_stepwidth_b = 0;
        dtmf_enable_pwm();
        
        sleep_ms(duration_ms / 3);
        _g_stepwidth_a = 43;    // E=659.26Hz
        sleep_ms(duration_ms / 3);
        _g_stepwidth_a = 51;    // G=784Hz
        sleep_ms(duration_ms / 3);
    }
    else if (digit == DIGIT_TUNE_DESC)
    {
        _g_stepwidth_a = 51;    // G=784Hz
        _g_stepwidth_b = 0;
        dtmf_enable_pwm();

        sleep_ms(duration_ms / 3);
        _g_stepwidth_a = 43;    // E=659.26Hz
        sleep_ms(duration_ms / 3);
        _g_stepwidth_a = 34;    // C=523.25Hz  
        sleep_ms(duration_ms / 3);
    }

    // Stop DTMF transmitting
    // Disable PWM output (compare match mode 0) and force it to 0
    TCCR0A &= ~_BV(COM0A1);
    TCCR0A &= ~_BV(COM0A0);
    PORTB &= ~_BV(PIN_PWM_OUT);
    
    _g_stepwidth_a = 0;
    _g_stepwidth_b = 0;

    GIMSK = _BV(INT0) | _BV(PCIE); 
}

// Enable PWM output by configuring compare match mode - non inverting PWM
static void dtmf_enable_pwm(void)
{
    TCCR0A |= _BV(COM0A1);
    TCCR0A &= ~_BV(COM0A0);
}
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

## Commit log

2026-04-24 Initial commit: ATTiny85 DTMF pulse dialer
    [pulse-dtmf.fzz]
2026-04-24 Store * and # in redial memory during normal dialing
    Previously * and # could only be stored in speed dial slots via manual
    programming, but were not saved to redial when dialed normally. Now both
    symbol types are stored in redial memory for consistent behavior.
2026-04-24 Save triggered speed dial to redial memory
    When a speed dial is triggered, also save it to redial memory so it
    can be easily redialed afterward. Skip if already dialing from redial
    to avoid redundant writes.
    [main.c]
2026-04-24 Add extra pause for menu navigation when dialing * or #
    When speed dial (or redial/hotline) contains * or #, add extra pause
    (1000ms by default) for menu navigation:
    - Extra pause BEFORE sending * or #
    - Extra pause continues for all subsequent digits after entering menu
    - Works for speed dial, redial, and hotline
    Configurable via MENU_EXTRA_PAUSE_MS in dtmf.h (currently 1000ms).
    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
2026-04-24 Initial commit: ATTiny85 DTMF pulse dialer
    Based on RotaryDial (https://bitbucket.org/310weber/rotary_dial/)
    Adds rotatone v2 hotdial and support for 'Erdtaste' (German special function):
    - Hotline: auto-dial a stored speed dial on power-up after configurable delay (0-9 sec)
    - Cancel hotline by pressing Earth key or starting to dial during startup
    - Store * and # in redial memory during normal dialing
    - Makefile renamed to pulse2dtmf.*
2026-04-24 Add pause insertion in speed dial memory - hold 1st beep then dial 0
2026-04-24 Fix DIGIT_PAUSE to 12 - outside normal digit range
    [dtmf.h, main.c]
2026-04-24 Insert pause on dial 3 in programming mode
2026-04-24 Simplify README: combine insert instructions
2026-04-24 Fix: handle DIGIT_PAUSE in dtmf_generate_tone to avoid processing as invalid
    [dtmf.c]
2026-04-24 Fix: disable WDT before redial pause to prevent MCU reset
    The watchdog timer was running with a 64ms timeout when redial was triggered.
    During the 2-second pause (DTMF_PAUSE_MS), the WDT would fire and reset
    the MCU mid-pause.
    Add wdt_stop() before dial_speed_dial_number() in three redial paths:
    - Erdtaste short press redial (Earth key)
    - SF 3 redial (dial 3 and hold)
    - Hotline auto-dial
    Also reordered DIGIT_PAUSE define in dtmf.h for consistency.
    [pulse-dtmf.fzz, pulse2dtmf.fzz]
2026-04-24 Fix: enable hotline clearing by handling dial 0 in STATE_HOTLINE_SLOT
    Previously, hotline clearing (dial 3, hold, dial 0) was broken because
    dial 0 was caught by the speed dial lookup before reaching the clearing
    code in STATE_SPECIAL_L2.
    Move the clearing logic to STATE_HOTLINE_SLOT where it actually runs,
    checking for dialed_digit == 0 before the speed dial lookup.
    Also remove dead code from STATE_SPECIAL_L2 that was never reachable.
    [main.c]
2026-04-24 Fix: separate hotline and SD clearing using special_hold_state
    - Separate hotline-clear and SD-clear into distinct guards using
    special_hold_state as discriminator
    - Add state stamps at L2 dispatch points so guards have meaningful values
    - Remove redundant hotline clear from STATE_HOTLINE_SLOT (now in L2)
    [main.c]
2026-04-24 Build: preserve EEPROM on chip erase, add erase target
    - Change hfuse from 0xDF to 0xD7 to set EESAVE fuse
    - Add erase target to erase only EEPROM without touching flash
    - Update .gitignore to exclude *.png and *.hex
2026-04-24 Fix: indicate empty SD slot with descending tone
    - Check if speed dial slot is empty before dialing
    - Play descending tone to indicate empty slot and return early
    - Avoids dialing empty slots that would produce no output
    [main.c]
2026-04-24 Build: fix erase target, use 2s L1 hold time, reset state after dialing
    Makefile:
    - Fix erase target to properly write 0xFF bytes to EEPROM
    - Add note reminding EEPROM is preserved after install
    main.c:
    - Change SPECIAL_L1 hold time from 1S to 2S for more reliable detection
    - Reset state to STATE_DIAL after speed dial/redial dialing completes
    - Ensures clean state transition after dialing operations
    [main.c]
2026-04-25 rename to erdtone and add new PCB
    - Rename output targets to erdtone (hex, elf)
    - Improve config feedback beeps with distinct timing patterns
    - Update README with proper branding and circuit section
    - Add new PCB layout (pcb.fzz, pcb-schematic.png, pcb-layout.png)
    - Remove legacy pulse2dtmf PCB files
    [pcb.fzz]
2026-04-26 Add automatic pause detection to redial memory and factory reset
    - Increase SPEED_DIAL_SIZE from 32 to 42 to accommodate stored pauses
    - Detect inter-digit pauses during normal dialing and automatically
    insert DIGIT_PAUSE into redial memory: one pause after ~3s, two
    after ~6s (capped at 2)
    - Pause detection uses single-shot WDT wakeups; the brief noise serves
    as audible feedback to the user that a pause was recorded
    - Add flush_pending_pauses() to write pending pauses before each digit
    is stored to redial
    - Fix flags = F_NONE in main loop, dial-at-rest block, ISR(INT0_vect)
    and suppress_first_release_if_needed() to use selective flag clearing,
    preserving F_DETECT_PAUSE across tra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
    [main.c]
2026-04-26 Add PIN-based lock feature with service codes
    - Add lock/unlock via *#PPP (3-digit PIN) during normal dial
    - Lock blocks normal dialing, programming, and factory reset
    - Speed dial, redial, hotline, and Earth key still work when locked
    - First *#PPP sets PIN and locks; same code unlocks
    - Wrong PIN gives no feedback
    - Factory reset (*#0#*) blocked when locked
    - Update README with service code documentation
    [main.c]
2026-04-26 Remove save_to_redial feature from dial_speed_dial_number()
    The save-to-redial functionality is no longer needed, so the parameter
    and associated code have been removed.
    [main.c]
2026-04-30 Add PIN entry mode for unlock from fully locked state
